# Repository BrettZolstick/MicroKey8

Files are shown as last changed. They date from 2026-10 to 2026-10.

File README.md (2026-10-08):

# MicroKey8
An 8 key rhythm game controller that uses microswitches commonly found in mice for short travel and advanced debounce logic.

<div align="center">

pcb
</div>

## Project Overview
## Build Instructions
## Firmware

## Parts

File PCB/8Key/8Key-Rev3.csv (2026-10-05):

Reference | Qty | Value | DNP | Exclude from BOM | Exclude from Board | Exclude from Simulation | Exclude from Position Files | Footprint | Datasheet | LCSC Part #
C1,C2 | 2 | 18p |  |  |  |  | ${EXCLUDE_FROM_POS_FILES} | Capacitor_SMD:C_0805_2012Metric |  | C1797
U2 | 1 | USB6B1 |  |  |  |  | ${EXCLUDE_FROM_POS_FILES} | Package_SO:SOIC-8_3.9x4.9mm_P1.27mm | http://www.st.com/content/ccc/resource/technical/document/datasheet/3e/ec/b2/54/b2/76/47/90/CD00001361.pdf/files/CD00001361.pdf/jcr:content/translations/en.CD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 | C10508
C7 | 1 | 10u |  |  |  |  | ${EXCLUDE_FROM_POS_FILES} | Capacitor_SMD:C_1206_3216Metric |  | C13585
C3 | 1 | 1u |  |  |  |  | ${EXCLUDE_FROM_POS_FILES} | Capacitor_SMD:C_0805_2012Metric |  | C28323
C4,C5,C6 | 3 | 100n |  |  |  |  | ${EXCLUDE_FROM_POS_FILES} | Capacitor_SMD:C_0805_2012Metric |  | C49678
Y1 | 1 | Crystal_GND24 |  |  |  |  | ${EXCLUDE_FROM_POS_FILES} | Crystal:Crystal_SMD_Abracon_ABM8G-4Pin_3.2x2.5mm |  | C112972
SW1 | 1 | SW_Push |  |  |  |  | ${EXCLUDE_FROM_POS_FILES} | Button_Switch_SMD:SW_Push_SPST_NO_Alps_SKRK |  | C115357
SW2,SW3,SW4,SW5,SW6,SW7,SW8,SW9 | 8 | SW_SPDT |  |  |  |  | ${EXCLUDE_FROM_POS_FILES} | PCM_openinput:SW_Micro_Switch |  | C397278
U1 | 1 | ATmega32U4-A | DNP |  |  |  | ${EXCLUDE_FROM_POS_FILES} | Package_QFP:TQFP-44_10x10mm_P0.8mm | http://ww1.microchip.com/downloads/en/DeviceDoc/Atmel-7766-8-bit-AVR-ATmega16U4-32U4_Datasheet.pdf | C2052746
R5,R6 | 2 | 5k1 |  |  |  |  | ${EXCLUDE_FROM_POS_FILES} | Resistor_SMD:R_0805_2012Metric |  | C2073749
R1,R2 | 2 | 10k |  |  |  |  | ${EXCLUDE_FROM_POS_FILES} | Resistor_SMD:R_0805_2012Metric |  | C2907219
R3,R4 | 2 | 22 |  |  |  |  | ${EXCLUDE_FROM_POS_FILES} | Resistor_SMD:R_0805_2012Metric |  | C2907310
J1 | 1 | USB_C_Receptacle_USB2.0_14P |  |  |  |  | ${EXCLUDE_FROM_POS_FILES} | Connector_USB:USB_C_Receptacle_GCT_USB4110 | https://www.usb.org/sites/default/files/documents/usb_type-c.zip | C5143397

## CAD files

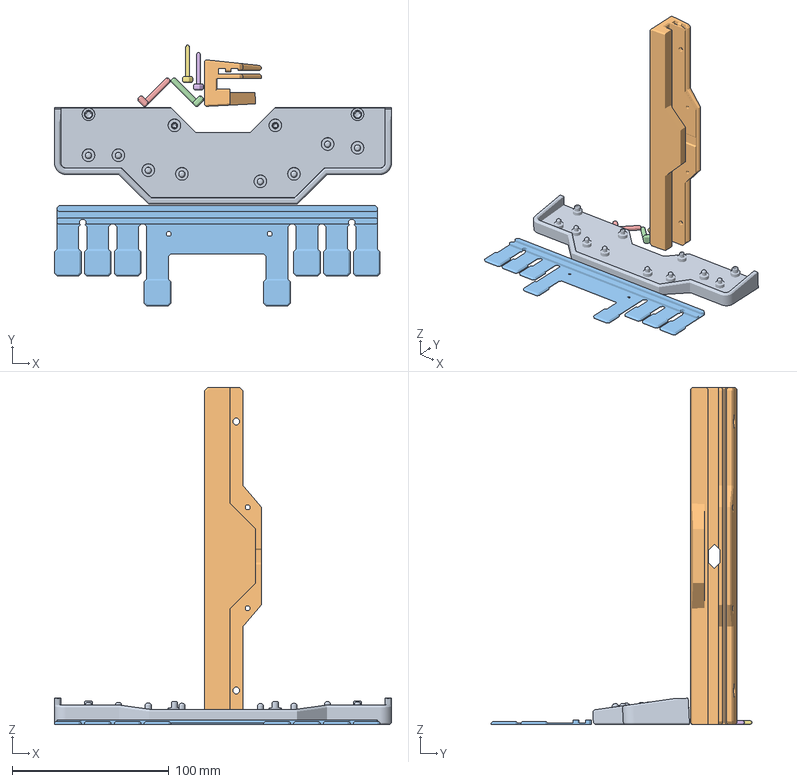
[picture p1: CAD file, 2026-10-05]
3d/Chassis.3mf
214.8 x 166.1 x 214.8 mm
Part Studio 2 - Base.stl
Part Studio 2 - Top.stl
Part Studio 2 - Leaf.stl
Part Studio 2 - Pin1.stl
Part Studio 2 - Pin4.stl
Part Studio 2 - Pin3.stl
Part Studio 2 - Pin2.stl

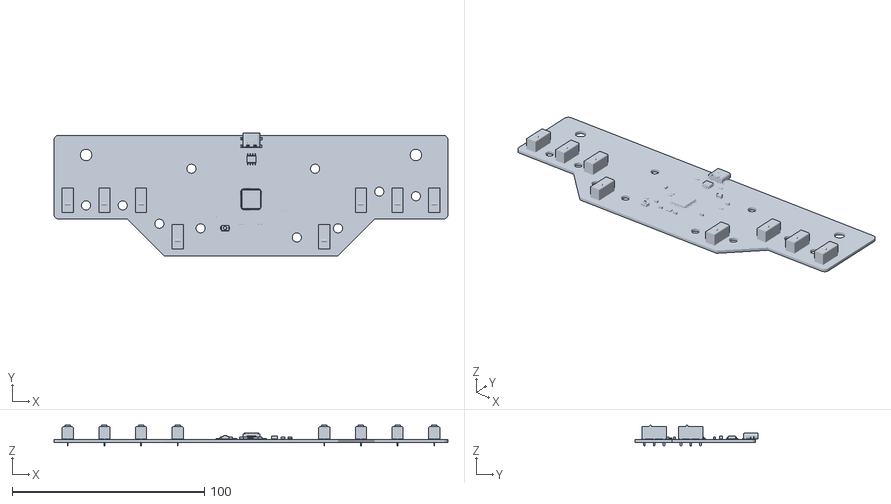
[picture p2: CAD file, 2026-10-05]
3d/PCB.stl
204.8 x 63.7 x 10.8

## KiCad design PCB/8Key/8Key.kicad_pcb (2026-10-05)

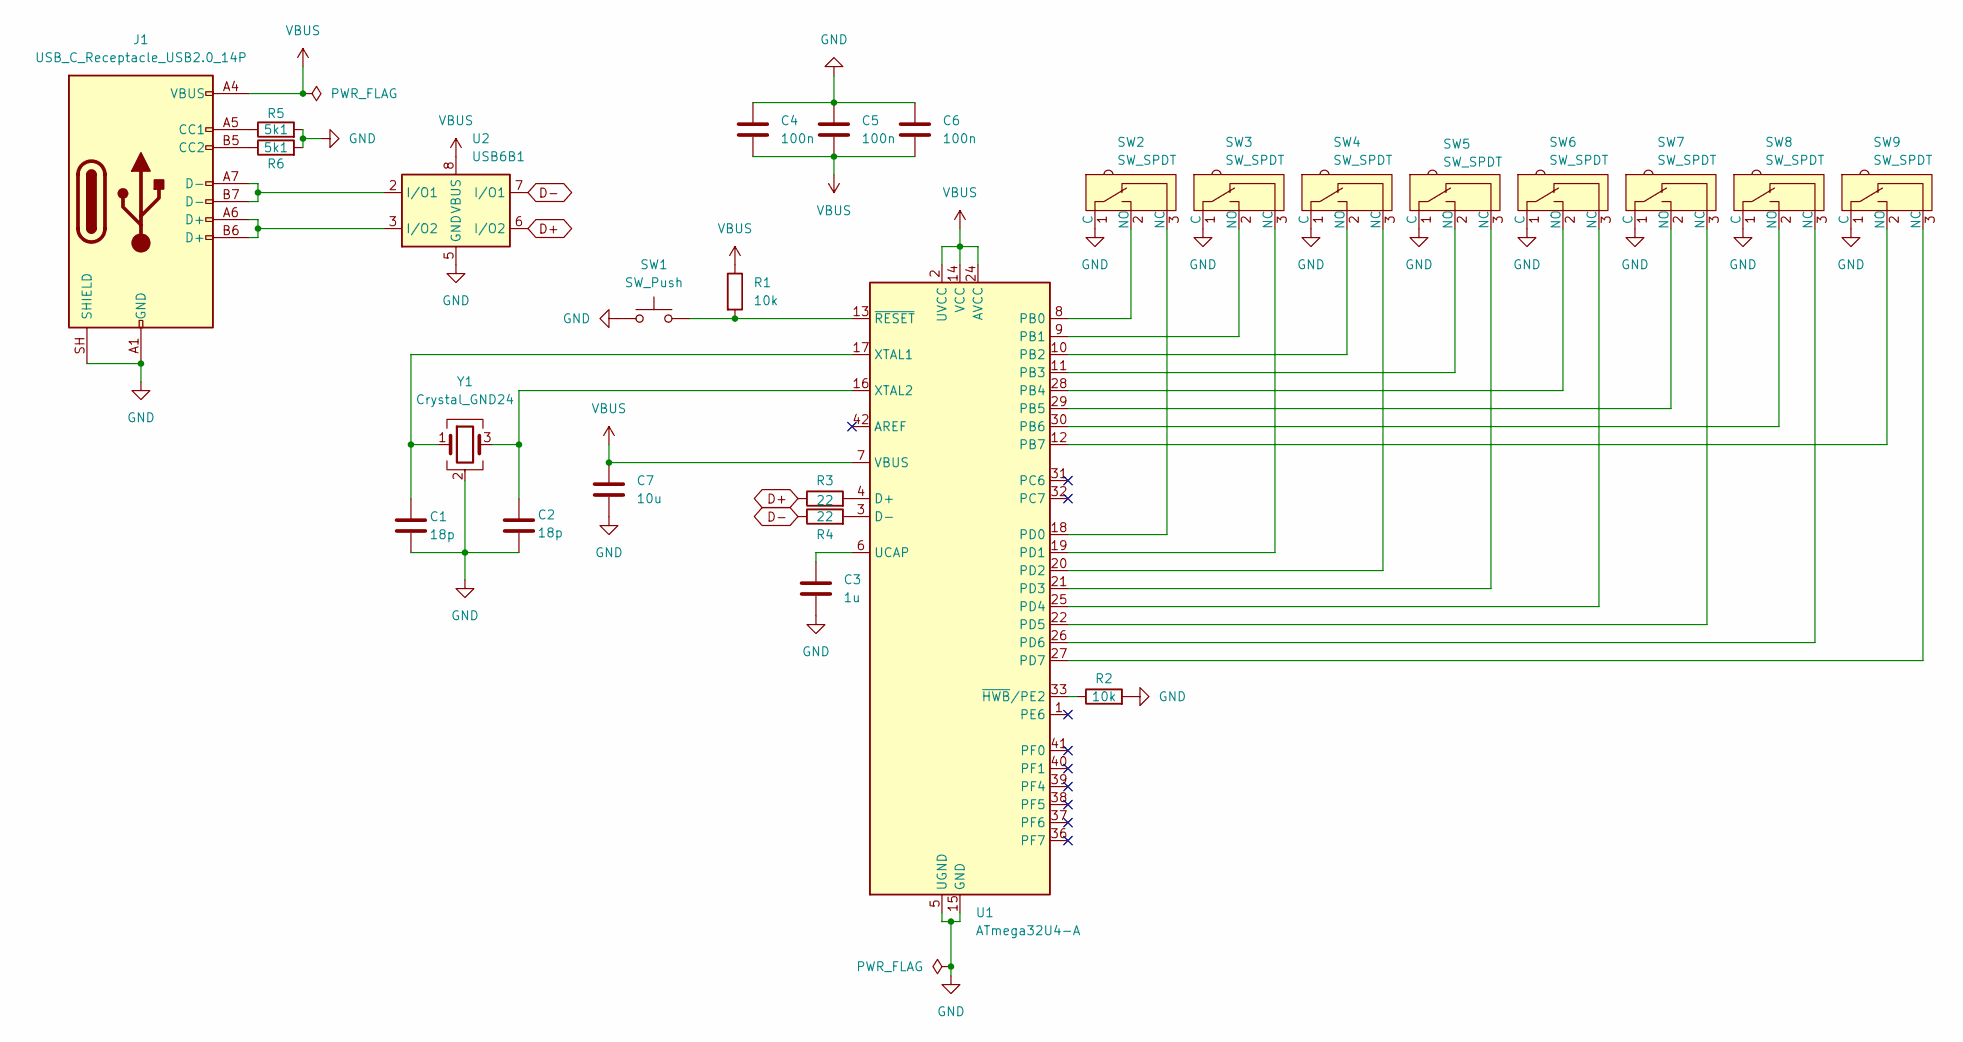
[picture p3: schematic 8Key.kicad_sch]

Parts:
C1, C2: 18p; C_0805_2012Metric; LCSC Part # C1797
C3: 1u; C_0805_2012Metric; LCSC Part # C28323
C4, C5, C6: 100n; C_0805_2012Metric; LCSC Part # C49678
C7: 10u; C_1206_3216Metric; LCSC Part # C13585
J1: USB_C_Receptacle_USB2.0_14P; USB_C_Receptacle_GCT_USB4110; LCSC Part # C5143397
R1, R2: 10k; R_0805_2012Metric; LCSC Part # C2907219
R3, R4: 22; R_0805_2012Metric; LCSC Part # C2907310
R5, R6: 5k1; R_0805_2012Metric; LCSC Part # C2073749
SW1: SW_Push; SW_Push_SPST_NO_Alps_SKRK; LCSC Part # C115357
SW2, SW3, SW4, SW5, SW6, SW7, SW8, SW9: SW_SPDT; SW_Micro_Switch; LCSC Part # C397278
U1: ATmega32U4-A; TQFP-44_10x10mm_P0.8mm; LCSC Part # C2052746
U2: USB6B1; SOIC-8_3.9x4.9mm_P1.27mm; LCSC Part # C10508
Y1: Crystal_GND24; Crystal_SMD_Abracon_ABM8G-4Pin_3.2x2.5mm; LCSC Part # C112972

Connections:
D+: R3.1, U2.6 (I/O2)
D-: R4.1, U2.7 (I/O1)
GND: C1.2, C2.2, C3.2, C4.1, C5.1, C6.1, C7.2, J1.A1 (GND), J1.A12 (GND), J1.B1 (GND), J1.B12 (GND), J1.SH (SHIELD), R2.2, R5.2, R6.2, SW1.1, SW2.1 (C), SW3.1 (C), SW4.1 (C), SW5.1 (C), SW6.1 (C), SW7.1 (C), SW8.1 (C), SW9.1 (C), U1.5 (UGND), U1.15 (GND), U1.23 (GND), U1.35 (GND), U1.43 (GND), U2.4 (GND), U2.5 (GND), Y1.2 (G), Y1.4 (G)
unnamed: J1.A5 (CC1), R5.1
unnamed: J1.B5 (CC2), R6.1
unnamed: J1.A6 (D+), J1.B6 (D+), U2.3 (I/O2)
unnamed: J1.A7 (D-), J1.B7 (D-), U2.2 (I/O1)
unnamed: SW2.3 (NC), U1.18 (PD0)
unnamed: SW2.2 (NO), U1.8 (PB0)
unnamed: SW3.3 (NC), U1.19 (PD1)
unnamed: SW3.2 (NO), U1.9 (PB1)
unnamed: SW4.3 (NC), U1.20 (PD2)
unnamed: SW4.2 (NO), U1.10 (PB2)
unnamed: SW5.3 (NC), U1.21 (PD3)
unnamed: SW5.2 (NO), U1.11 (PB3)
unnamed: SW6.3 (NC), U1.25 (PD4)
unnamed: SW6.2 (NO), U1.28 (PB4)
unnamed: SW7.3 (NC), U1.22 (PD5)
unnamed: SW7.2 (NO), U1.29 (PB5)
unnamed: SW8.3 (NC), U1.26 (PD6)
unnamed: SW8.2 (NO), U1.30 (PB6)
unnamed: SW9.3 (NC), U1.27 (PD7)
unnamed: SW9.2 (NO), U1.12 (PB7)
unnamed: R3.2, U1.4 (D+)
unnamed: R4.2, U1.3 (D-)
unnamed: C3.1, U1.6 (UCAP)
unnamed: C1.1, U1.17 (XTAL1), Y1.1
unnamed: C2.1, U1.16 (XTAL2), Y1.3
unnamed: R2.1, U1.33 (~HWB/PE2)
unnamed: R1.2, SW1.2, U1.13 (~RESET)
VBUS: C4.2, C5.2, C6.2, C7.1, J1.A4 (VBUS), J1.A9 (VBUS), J1.B4 (VBUS), J1.B9 (VBUS), R1.1, U1.2 (UVCC), U1.7 (VBUS), U1.14 (VCC), U1.24 (AVCC), U1.34 (VCC), U1.44 (AVCC), U2.1 (VBUS), U2.8 (VBUS)

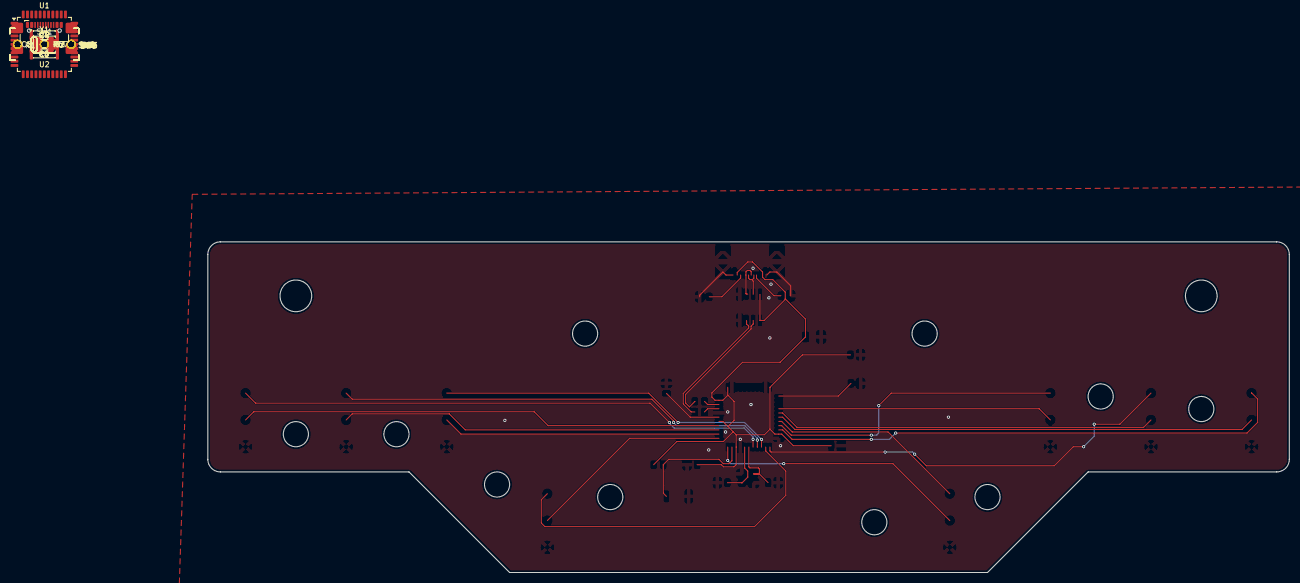
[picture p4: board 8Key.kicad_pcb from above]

Board: 2 copper layers, 204.8 x 62.6 mm, 26 parts (0 on the bottom side), 31 nets.

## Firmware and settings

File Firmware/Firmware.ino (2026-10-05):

#include <Arduino.h>
#include <Keyboard.h>
#include <avr/io.h>
#include <avr/wdt.h>
#include <avr/interrupt.h>

void setup() {

  // Running into a bug where the MCU's watchdog keeps thinking the program is stuck.
  // It keeps forcing a reset every time it boots. Disabling the watchdog timer fixes this.
  // 
  // Clear the watchdog reset flag and then disable the watchdog timer.
  MCUSR &= ~(1 << WDRF);
  wdt_disable();

  // The ATMEGA32U4 has a System Clock Prescaler, which divides the clock by a set amount.
  // By default, it divides by 8. Its 16Mhz signal from the crystal goes down to 2Mhz.
  // This can be overwritten with a special proceedure. (see 6.8.1 and 6.11.4 in the ATMEGA32U4's datasheet)
  //
  //   CLKPR is the Clock Prescaler Register
  //   7 (CLKPCE)  | 6 -         | 5 -         | 4 -         | 3 (CLKPS3)  | 2 (CLKPS2)  | 1 (CLKPS1)  | 0 (CLKPS0)
  //   R/W           R             R             R             R/W           R/W           R/W           R/W
  //   0             0             0             0             0             0             1             1
  // 
  //   See Table 6-10  for available division factors(6.11.4 in datasheet)
  //
  // In this case, CLKPS3..0 need to be set to 0000 for a division factor of 1 so it runs at it's full 16Mhz
  // 
  //
  // Temporarily disable interrupts (clear interrupt flag)
  cli();
  // Set Clock Prescaler Change Enable (CLKPCE) to 1 and all other CLKPR bits to 0
  CLKPR = (1 << CLKPCE);
  // Within 4 clock cycles, write the desired value to CLKPS3..0 while writing a 0 to CLKPCE
  CLKPR = 0; // 00000000 = divide by 1
  // Re-enable interrupts (set interrupt flag)
  sei();

  // Configure all the GPIO pins that will be needed
  DDRB = 0b00000000; // set registers B and D as inputs
  DDRD = 0b00000000;
  PORTB = 0b11111111; // enable the internal pull-up resistors on registers B and D 
  PORTD = 0b11111111;

  // Enable the serial monitor and send a message (/dev/ttyACM*)
  Serial.begin(9600);
  delay(1000);
  Serial.println("initialized");
}


unsigned long debounceMicros = 2000;

struct Switch {
  byte pin;

  char key;

  bool topState;
  bool bottomState;

  bool switchState;
  bool previousSwitchState;

  unsigned long switchStateChangeTimestamp;
};
void readPins(Switch &sw);
void getSwitchState(Switch &sw);
void updateSwitchState(Switch &sw);

void readPins(Switch &sw) {
    uint8_t mask = (1 << sw.pin); // create a mask for only the pin that you want to read
    sw.topState = ((PIND & mask) != 0); // And the two 8 bit values, if its not 00000000, then the masked pin must be 1
    sw.bottomState = ((PINB & mask) != 0); // 0 = contact with ground, 1 = no contact
}

void getSwitchState(Switch &sw){
  // if the switch is currently unpressed, change it to be pressed as soon as the top contact breaks
  if (!sw.switchState) {
    if (sw.topState){
      sw.switchState = true;
    }
  }
  // if the switch is currently pressed, change it to be unpressed as soon as the bottom contact breaks
  if (sw.switchState) {
    if (sw.bottomState){
      sw.switchState = false;
    }
  }
}

void updateSwitchState(Switch &sw){
  // exit if no change
  if (sw.switchState == sw.previousSwitchState){
    return;
  }

  // exit if during the debounce timeframe
  if ((micros() - sw.switchStateChangeTimestamp) < debounceMicros ){
    return;
  }

  // otherwise, send key press
  sw.switchStateChangeTimestamp = micros();
  if (sw.switchState){
    Keyboard.press(sw.key);
  }else{
    Keyboard.release(sw.key);
  }

  // set previous switch state for the next loop
  sw.previousSwitchState = sw.switchState;
}

Switch switches[] = {
  {0,'a'},
  {1,'s'},
  {2,'d'},
  {3,'v'},
  {4,';'},
  {5,'l'},
  {6,'k'},
  {7,'n'},
};

void loop() {

  for (int i = 0; i < 8; i++){
    readPins(switches[i]);
    getSwitchState(switches[i]);
    updateSwitchState(switches[i]);
  }
}
